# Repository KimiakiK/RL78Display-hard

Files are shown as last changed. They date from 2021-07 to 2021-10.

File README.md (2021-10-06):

# RL78Display-hard

## パーツリスト
- [RL78/G13 R5F100LLAFA 512KB/32KB](https://www.marutsu.co.jp/pc/i/226841/)
- [TFT 1.3inch 240x240](https://akizukidenshi.com/catalog/g/gP-15695/)
- [RTC IC RX8900CE](https://akizukidenshi.com/catalog/g/gI-13320/)
- タッチセンサIC TTP223
- [コネクタ FFC Bottom 12極 0.5mm](https://www.marutsu.co.jp/pc/i/15778034/)
- [表面実装圧電ブザー](https://akizukidenshi.com/catalog/g/gP-14238/)
- [水晶発振子 32.768kHz](https://akizukidenshi.com/catalog/g/gP-07195/)
- [レギュレータ 3.3V 500mA SOT89-5 NJM2884U1-33](https://akizukidenshi.com/catalog/g/gI-10673/)
- [レギュレータ 3.0V 100mA SOT-23-5 NJM2864F03](https://akizukidenshi.com/catalog/g/gI-16314/)
- [マイクロUSBコネクタ](https://akizukidenshi.com/catalog/g/gC-11183/)
- [ミニUSBコネクタ](https://akizukidenshi.com/catalog/g/gC-05690/)
- [NchパワーMOSFET SOT-23](https://akizukidenshi.com/catalog/g/gI-14653/)
- [青色チップLED 1608](https://akizukidenshi.com/catalog/g/gI-11881)
- [白色チップLED 1608](https://akizukidenshi.com/catalog/g/gI-11882)
- [コンデンサ 0.22F 3.3V](https://akizukidenshi.com/catalog/g/gP-00240/)
- [チップコンデンサ 2.2uF 1608](https://akizukidenshi.com/catalog/g/gP-16077/)
- [チップコンデンサ 1uF 1608](https://akizukidenshi.com/catalog/g/gP-14526/)
- [チップコンデンサ 0.1uF 1608](https://akizukidenshi.com/catalog/g/gP-13374/)
- [チップコンデンサ 330pF 1608](https://akizukidenshi.com/catalog/g/gP-05584/)
- [チップコンデンサ 10pF 1005](https://akizukidenshi.com/catalog/g/gP-13400/)
- [フェライトビーズBLM18PPG600SN 1608](https://akizukidenshi.com/catalog/g/gP-04442/)
- [リセッタブルヒューズ 9V 200mA 1608](https://akizukidenshi.com/catalog/g/gP-14311/)

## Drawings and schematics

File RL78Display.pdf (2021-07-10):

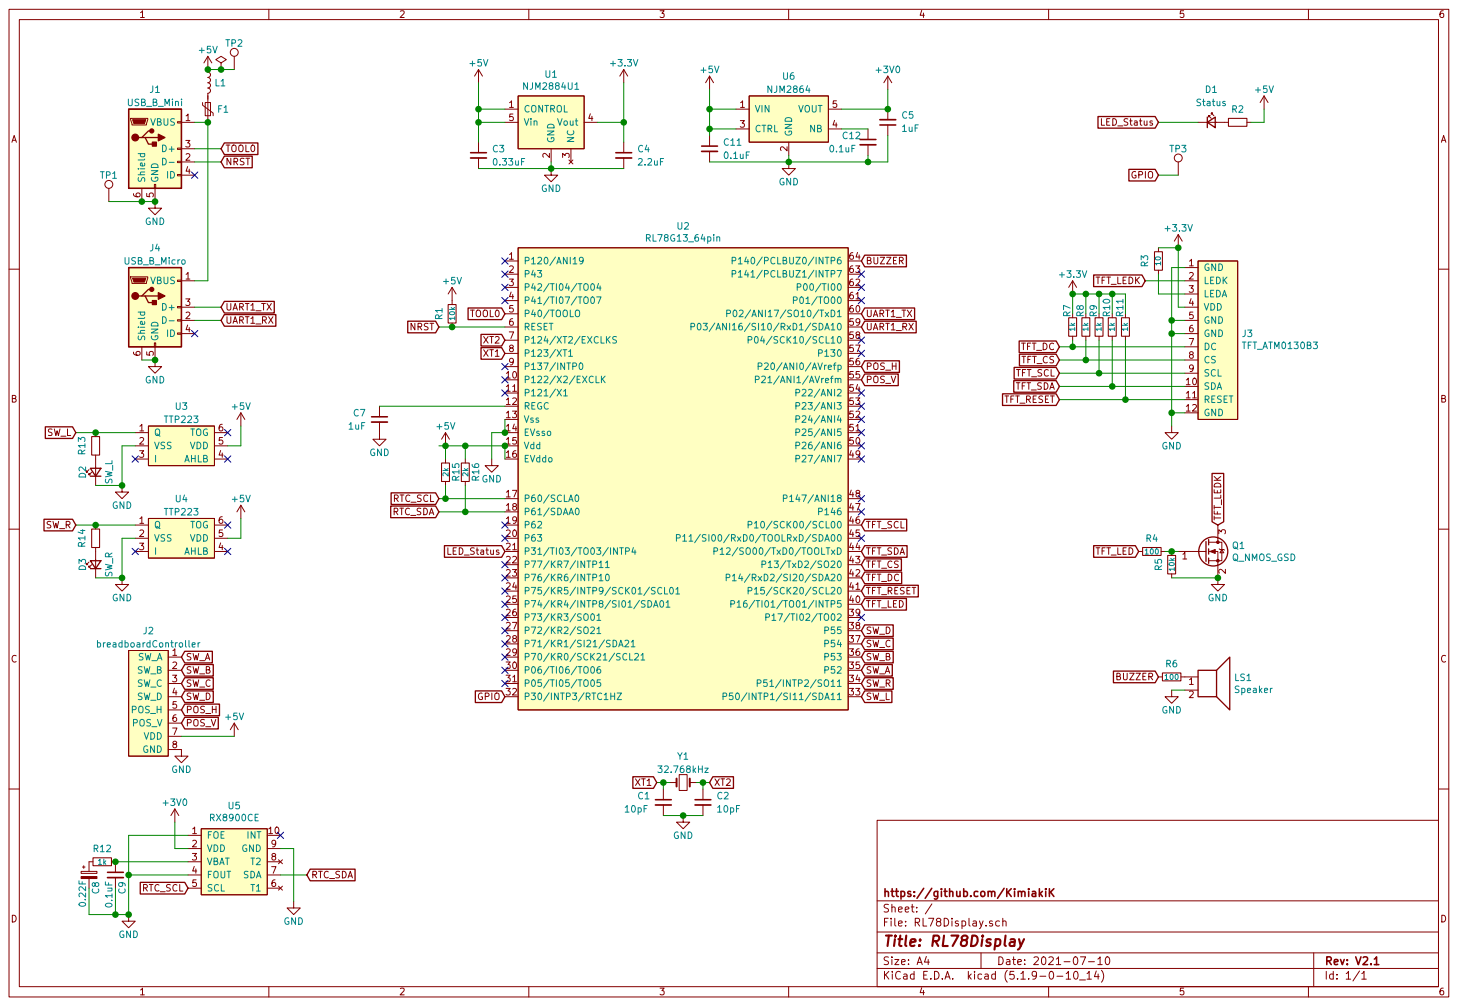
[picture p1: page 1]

File: RL78Display.sch Sheet: / https://github.com/KimiakiK

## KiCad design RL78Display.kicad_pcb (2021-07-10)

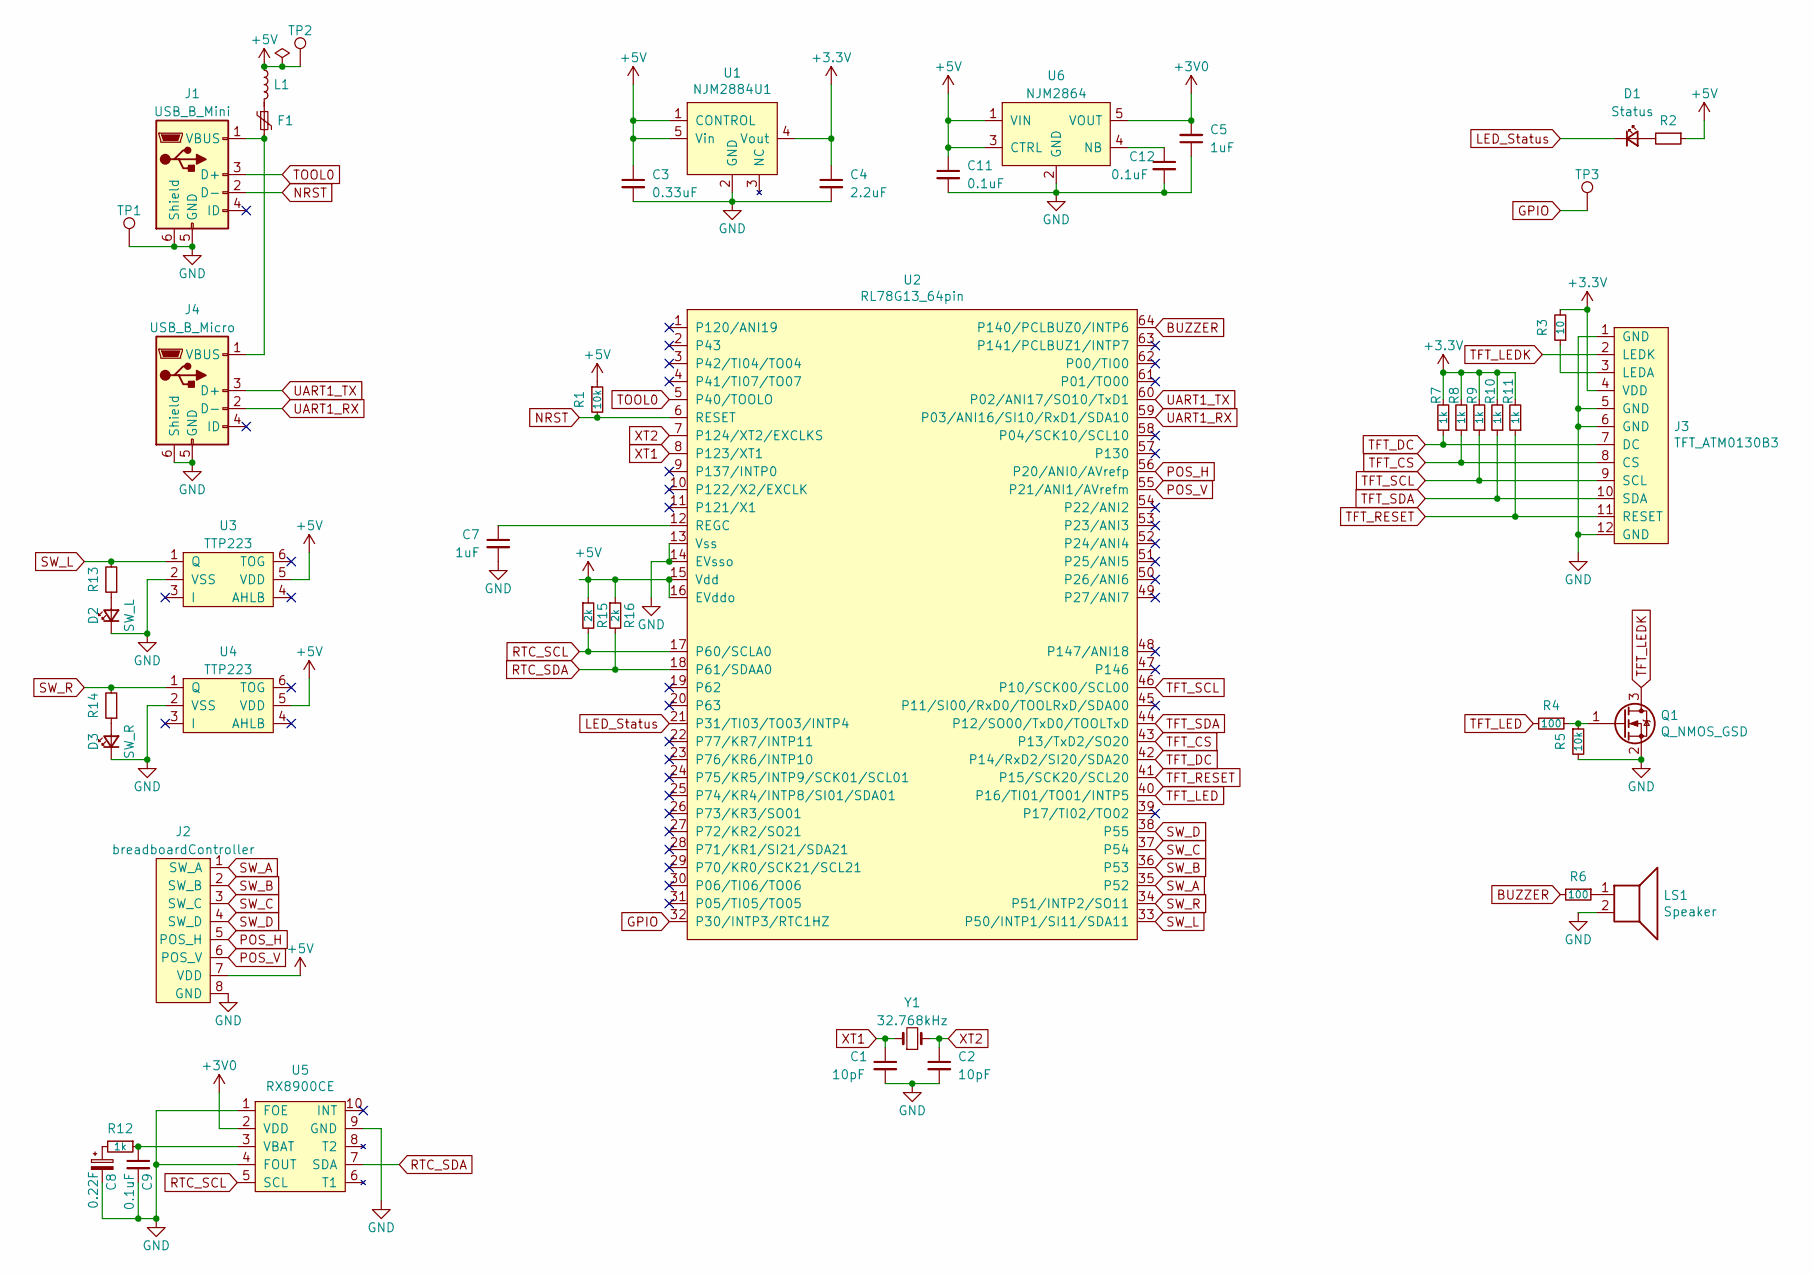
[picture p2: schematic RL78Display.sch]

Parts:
C1, C2: 10pF; 1005Metric
C3: 0.33uF; 1608Metric
C4: 2.2uF; 1608Metric
C5, C7: 1uF; 1608Metric
C8: 0.22F; DCK-3R3E224-E
C9, C11, C12: 0.1uF; 1608Metric
D1: Status; 1608Metric
D2: SW_L; 1608Metric
D3: SW_R; 1608Metric
F1: Polyfuse_Small; 1608Metric
J1: USB_B_Mini; UX60SC-MB-5ST
J2: breadboardController; PinHeader_1x08_P2.54mm_Vertical
J3: TFT_ATM0130B3; Hirose_FH12-12S-0.5SH_1x12-1MP_P0.50mm_Horizontal
J4: USB_B_Micro; ZX62-B-5PA
L1: L_Small; 1608Metric
LS1: Speaker; PKMCS0909E4000
Q1: Q_NMOS_GSD; SOT-23
R1, R5: 10k; 1608Metric
R2, R13, R14: R; 1608Metric
R3: 10; 1608Metric
R4, R6: 100; 1608Metric
R7, R8, R9, R10, R11, R12: 1k; 1608Metric
R15, R16: 2k; 1608Metric
TP1, TP2, TP3: TestPoint; TestPoint_THTPad_D1.4mm_Drill0.8mm
U1: NJM2884U1; SOT-89-5
U2: RL78G13_64pin; LQFP-64-12x12nn-P0.65mm_FusionPCB
U3, U4: TTP223; SOT-23-6
U5: RX8900CE
U6: NJM2864; SOT-23-5
Y1: 32.768kHz; Crystal_SMD_3215-2Pin

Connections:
+3V0: C5.2, U5.2 (VDD), U6.5 (VOUT)
+3V3: C4.1, J3.4 (VDD), R3.2, R7.2, R8.2, R9.2, R10.2, R11.2, U1.4 (Vout)
+5V: C3.1, C11.1, J2.7 (VDD), L1.1, R1.1, R2.1, R15.1, R16.1, TP2.1, U1.1 (CONTROL), U1.5 (Vin), U2.15 (Vdd), U2.16 (EVddo), U3.5 (VDD), U4.5 (VDD), U6.1 (VIN), U6.3 (CTRL)
BUZZER: R6.2, U2.64 (P140/PCLBUZ0/INTP6)
GND: C1.2, C2.2, C3.2, C4.2, C5.1, C7.2, C8.2, C9.2, C11.2, C12.2, D2.1 (K), D3.1 (K), J1.5 (GND), J1.6 (Shield), J2.8 (GND), J3.1 (GND), J3.5 (GND), J3.6 (GND), J3.12 (GND), J4.5 (GND), J4.6 (Shield), LS1.2, Q1.2 (S), R5.2, TP1.1, U1.2 (GND), U2.13 (Vss), U2.14 (EVsso), U3.2 (VSS), U4.2 (VSS), U5.1 (FOE), U5.4 (FOUT), U5.9 (GND), U6.2 (GND)
GPIO: TP3.1, U2.32 (P30/INTP3/RTC1HZ)
LED_Status: D1.1 (K), U2.21 (P31/TI03/TO03/INTP4)
NRST: J1.2 (D-), R1.2, U2.6 (RESET)
unnamed: C7.1, U2.12 (REGC)
unnamed: C8.1, R12.2
unnamed: C9.1, R12.1, U5.3 (VBAT)
unnamed: C12.1, U6.4 (NB)
unnamed: D1.2 (A), R2.2
unnamed: D2.2 (A), R13.1
unnamed: D3.2 (A), R14.1
unnamed: F1.1, L1.2
unnamed: F1.2, J1.1 (VBUS), J4.1 (VBUS)
unnamed: J3.3 (LEDA), R3.1
unnamed: LS1.1, R6.1
unnamed: Q1.1 (G), R4.1, R5.1
POS_H: J2.5 (POS_H), U2.56 (P20/ANI0/AVrefp)
POS_V: J2.6 (POS_V), U2.55 (P21/ANI1/AVrefm)
RTC_SCL: R15.2, U2.17 (P60/SCLA0), U5.5 (SCL)
RTC_SDA: R16.2, U2.18 (P61/SDAA0), U5.7 (SDA)
SW_A: J2.1 (SW_A), U2.35 (P52)
SW_B: J2.2 (SW_B), U2.36 (P53)
SW_C: J2.3 (SW_C), U2.37 (P54)
SW_D: J2.4 (SW_D), U2.38 (P55)
SW_L: R13.2, U2.33 (P50/INTP1/SI11/SDA11), U3.1 (Q)
SW_R: R14.2, U2.34 (P51/INTP2/SO11), U4.1 (Q)
TFT_CS: J3.8 (CS), R8.1, U2.43 (P13/TxD2/SO20)
TFT_DC: J3.7 (DC), R7.1, U2.42 (P14/RxD2/SI20/SDA20)
TFT_LED: R4.2, U2.40 (P16/TI01/TO01/INTP5)
TFT_LEDK: J3.2 (LEDK), Q1.3 (D)
TFT_RESET: J3.11 (RESET), R11.1, U2.41 (P15/SCK20/SCL20)
TFT_SCL: J3.9 (SCL), R9.1, U2.46 (P10/SCK00/SCL00)
TFT_SDA: J3.10 (SDA), R10.1, U2.44 (P12/SO00/TxD0/TOOLTxD)
TOOL0: J1.3 (D+), U2.5 (P40/TOOLO)
UART1_RX: J4.2 (D-), U2.59 (P03/ANI16/SI10/RxD1/SDA10)
UART1_TX: J4.3 (D+), U2.60 (P02/ANI17/SO10/TxD1)
XT1: C1.1, U2.8 (P123/XT1), Y1.1
XT2: C2.1, U2.7 (P124/XT2/EXCLKS), Y1.2

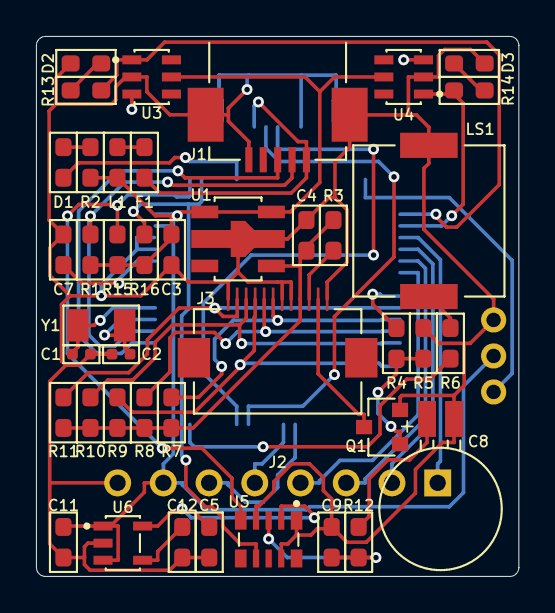
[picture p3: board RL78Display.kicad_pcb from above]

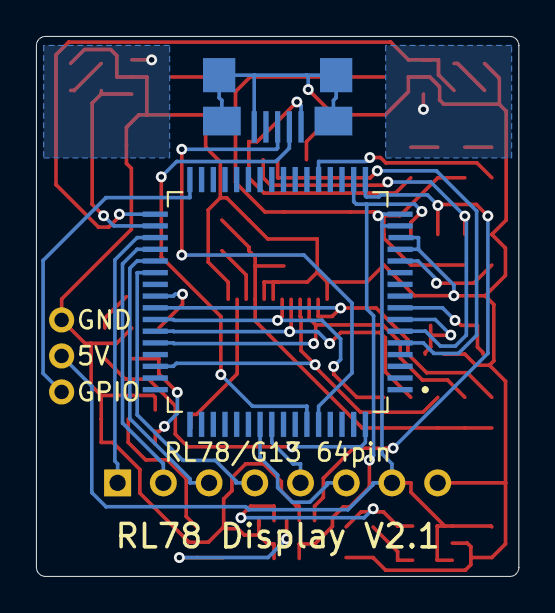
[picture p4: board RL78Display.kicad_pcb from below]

Board: 2 copper layers, 26.8 x 30.0 mm, 47 parts (5 on the bottom side), 42 nets.

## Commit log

2021-04-11 基板 V1.0
    [RL78Display-B_Cu.gbl, RL78Display-B_Mask.gbs, RL78Display-B_Paste.gbp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]
2021-05-27 基板 V1.1
    [RL78Display-B_Cu.gbl, RL78Display-B_Mask.gbs, RL78Display-B_Paste.gbp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]
2021-06-20 基板 V2.0
    [RL78Display-B_Cu.gbl, RL78Display-B_Mask.gbs, RL78Display-B_Paste.gbp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]
2021-07-10 基板 V2.1
    [RL78Display-B_Cu.gbl, RL78Display-B_Mask.gbs, RL78Display-B_Paste.gbp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]
2021-10-06 パーツリスト追加
